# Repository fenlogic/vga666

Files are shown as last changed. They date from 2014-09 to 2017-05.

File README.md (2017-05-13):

# vga666

Passive VGA adapter 666 for Raspberry-Pi B+

## Licence

VGA adaptor for the Raspberry-Pi computer.

Copyright © 2014 Fen Logic Ltd. 

This document and the related databases are free: you can redistribute it and/or modify it under the terms of the GNU General Public License as published by the Free Software Foundation, either version 3 of the License, or any later version. This document and the related databases are distributed in the hope that it will be useful, but WITHOUT ANY WARRANTY; without even the implied warranty of MERCHANTABILITY or FITNESS FOR A PARTICULAR PURPOSE. See the GNU General Public License for more details. You should have received a copy of the GNU General Public License along with this database. If not, see http://www.gnu.org/licenses/

## Usage

For the latest information how to use the VGA adapter see: 
https://www.raspberrypi.org/forums/viewtopic.php?f=91&t=94424&start=125#p657497

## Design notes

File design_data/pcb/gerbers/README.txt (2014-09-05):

bot.pho : Copper bottom.
dd.pho  : Drill data.
smb.pho : Solder mask bottom.
smt.pho : Solder mask top.
ssb.pho : Silkscreen bottom.
sst.pho : Silkscreen top
top.pho : Copper top.

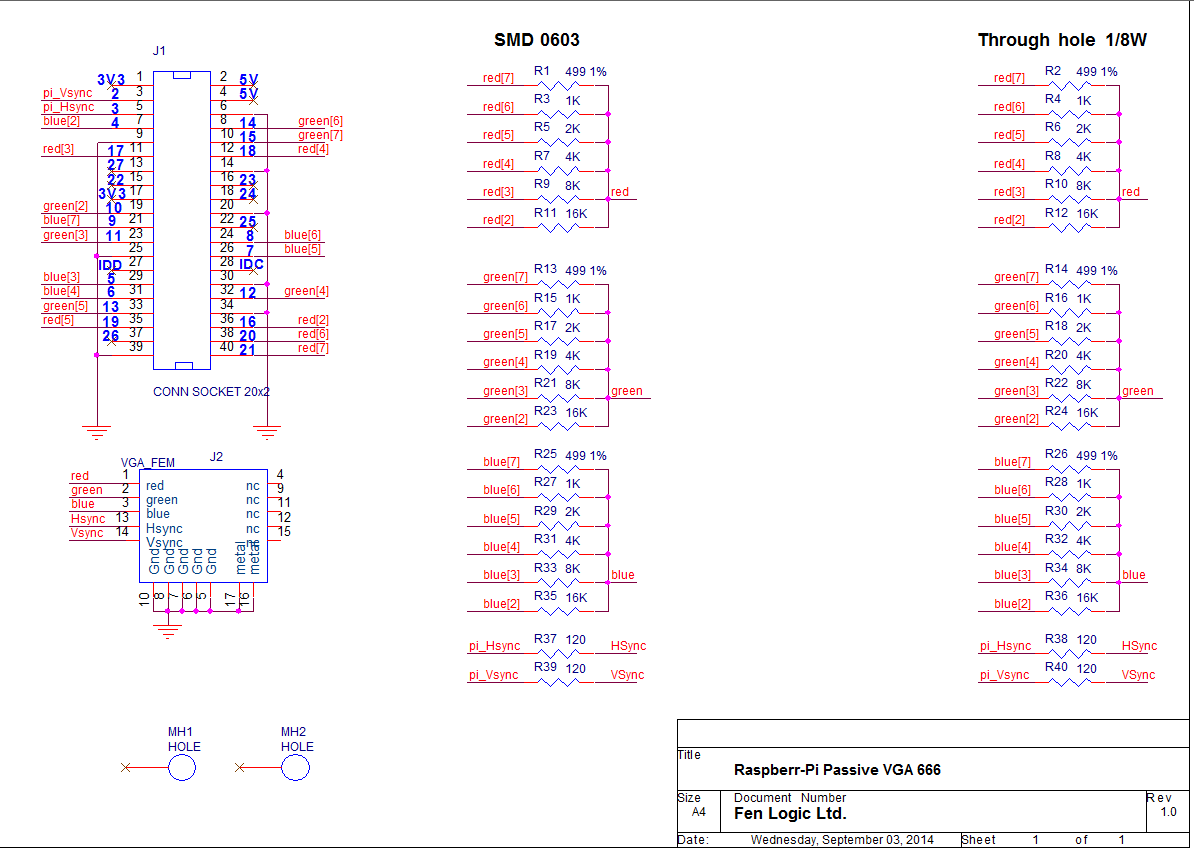
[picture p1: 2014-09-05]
design_data/schematic/vga.gif

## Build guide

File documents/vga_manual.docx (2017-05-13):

Raspberry-Pi VGA

Fen Logic Ltd.

8 September 2014

G.J. van Loo

# Introduction

The GNU GPLv3 license is applicable to this manual and the related databases:

VGA adaptor for the Raspberry-Pi computer.

Copyright © 2014 Fen Logic Ltd.

This document and the related databases are free: you can redistribute it and/or modify it under the terms of the GNU General Public License as published by the Free Software Foundation, either version 3 of the License, or any later version. This document and the related databases are distributed in the hope that it will be useful, but WITHOUT ANY WARRANTY; without even the implied warranty of MERCHANTABILITY or FITNESS FOR A PARTICULAR PURPOSE. See the GNU General Public License for more details. You should have received a copy of the GNU General Public License along with this database. If not, see http://www.gnu.org/licenses/

Thus like with the GNU software, you can replicate this hardware, make derivatives etc. All I ask is that the original designer (Fen Logic Ltd.) gets mentioned in any direct or indirect copies of this work. Note that the GPLv3 mentions: "The GNU General Public License is a free, copyleft license for software and other kinds of works." For contact about this document and/or the databases: info@fenlogic.com.

The adapter (all SMD resistors are at the other side of the board)

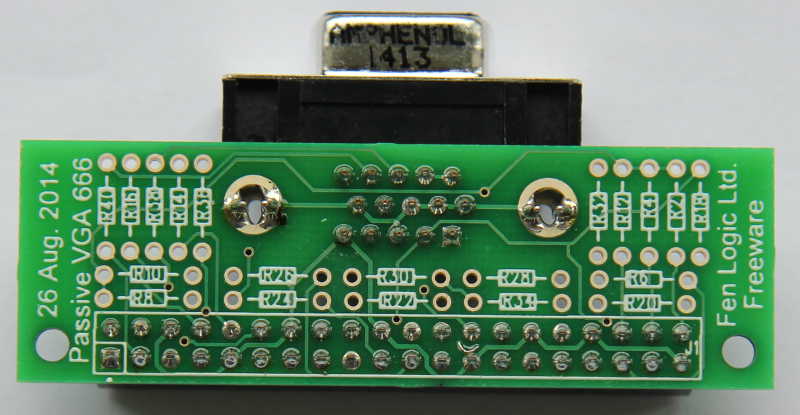
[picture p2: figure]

# Information

VGA

From the birth of the Raspberry-Pi there have been complaints about the lack of a VGA output. That has now been remedied. But only for the B+ and at the cost of losing most of your GPIOs.

The BCM2835 has a parallel display interface on the GPIO pins. I did not publish this in the 2835 datasheet as 50% of the DPI pins where not on the GPIO connector, making it impossible to get any decent video out. The B+ however has all of the necessary DPI signals brought out. Dom has been working on the software side and the new DPI (read: VGA) driver software has been added to the latest release.

Resolution & Quality

The VGA output supports the same resolutions as your HDMI one. Thus from 640x480 up to 1920x1024 60fps. At the highest resolution the pixel quality is almost as good as HDMI. If you look very closely there is a slight pixel crawl. The adapter uses a simple resistor ladder network as digital-to-analogue converter. Therefore the colour quality depends on how well balanced your resistors are. The video shown uses an adapter with 1% SMD resistors. There is a slight colour banding and with 6 bits per channel you have a maximum of 262144 colours.

Double screen

In contrast to the composite video, the DPI interface can be run independent of the HDMI. Thus next to the HDMI screen, the VGA can be used as ‘second monitor’. The software for that is still under development but I expect that to arrive in the next two week. Beware that running two screens at maximum resolution will really eat into your SDRAM bandwidth. In fact it has not tried yet, so it might not be possible.

Where to buy

Nowhere: you can’t buy this anywhere for several reasons which you can find in the manual. But you can make it yourself, or find yourself an enthusiastic partner and have it made. All the data is in the public domain at Github: https://github.com/fenlogic/vga666 . Besides the usual: (Manual, schematics), you will also find the data base for the PCB and the Gerber files. The PCB design supports both through-hole and SMD parts. The design consists of:

- 1 PCB
- 2 connectors
- 20 resistor.

The cost is not prohibited but having a single PCB made is rather expensive so you might want to collect a group of interested people and order a batch. I expect in due time that a far-east manufacturer sees fit to sell them for two dollars. (Batteries not included).

I am in contact with a PCB manufacturer who might put the PCB in their on-line shop for direct purchase.

## Design

The design database consists of:

- design_data/schematic/vga.opj Cadence 16.6 project file
- design_data/schematic/vga.dsn Cadence 16.6 schematics database
- design_data/schematic/vga.gif Screendump of schematic.
- design_data/pcb/VGA.pcb Pads 9.4 PCB database
- design_data/pcb/gerbers/* gerber files, RS-274-X format & readme.
- documents/vga_manual.docx This manual (word 2013)
- documents/vga_manual.pdf This manual (pdf).

## Notes

The schematic below shows two columns of resistors. You can mix through-hole or SMD but for each signal you should mount only one resistor. Thus one of R1 or R2. One of R3 or R4 etc.

The design violates the GPIO specification. You should not draw more than 16mA from a pin. Thus the minimum resistor is 3.3/0.016 = 206 Ohms. But you will notice that the HSYNC and VSYNC resistor are less. I tried 200 Ohm but found that it does not work on some monitors. On the prototype I used 100 Ohm resistors, you might even have to go down to 80 ohms.

The PCB is NOT EMC tested and is likely to radiate a lot. Fortunately the EMC rules do not apply for home-made electronics. But still you might keep it away from sensitive electronics.

The quality from the colours greatly depends on how accurate your resistors are. Certainly the 499 Ohm should be 1% accurate. You might want to use 500Ohm instead but at 1% that is about the same as 499Ohm. The 500 Ohm ones are a lot more difficult (and expensive) to obtain.

## Calculations

If you use a different number of GPIO pins the resistor values have to change. These calculations might help you with that. The impedance of a VGA monitors is 75 Ohms for the colour signals. The Raspberry-Pi has 3.3 volts coming out of the GPIO pins. The VGA colours signal should be 700mV. From that we can calculate what the series resistor should be: Rs = 3.3/0.7*75-75 = 278 Ohms. The series resistors are split into 6 values in the ratio of 1:2:4:8:16:32. These values are placed in parallel.

1/Rs = 1/x + 1/2x + 1/4x + 1/8x + 1/16x + 1/32x A bit of maths gives us that x = 547 Ohms. Thus officially we need resistor value of 547, 1094, 2189, 4378, 8757, 17514 ohms. But those are difficult to obtain so I rounded down to 500, 1K, 2K, 4K, 8K and 16K.

The value of the Hsync and Vsycn resistors have been determined empirical.

## FAQ

How much CPU power does it use?

Non more than the HDMI output. The video signal is generated by the DPI peripheral, not by bit-bashing the GPIO pins. However the DPI interface has a much shallower FIFO and thus it is more likely that the driver does not gets its data in time from the SDRAM (underrun). This shows up as a horizontal ‘hick-up’ on the screen.

How many GPIO pins does it use?

It uses the GPIO pins 2-21. Thus you only have 6 GPIO pins left: 22..27.

Can I use it on the A or B?

No, it only works on the B+. It is no so much the number of GPIO pins required, the right GPIO pins are required. The VGA output must have access to at least the MS bits of each colour channel and on the A and B these are not on the GPIO header for all three colours.

Can I use it with the computer module?

The board will not plug into the computer module as that does not have a GPIO header. But you can connect the GPIO pins as in the schematic.

Does it work with Minecraft?

Yes, although Minecraft on the Pi writes directly to an image buffer the VGA handling is the same as the HDMI. (Yes, I tried it :-)

Can I have two independent screens?

Ultimately yes. At the moment the drivers for two independent screens are under development. (In the demo video we cheated a bit). . Running two screens (or three with the DSI screen?) will use up a lot of SDRAM bandwidth and not all resolutions on all screens will be possible.

Will it work for XBMC?

Yes, I have been told the change are already in the latest release.

Can I reduce the number of GPIO pins it uses?

Yes. You can drop the LS colours bits of each channel which will free up more GPIO pins but the picture quality will get worse as you lose more colours. If you use less resistors you also have to adapt the values. (See section: Calculations).

Bits/channel | Colours
6 | 262144
5 | 32768
4 | 4096
3 | 512
2 | 64
1 | 8

Schematic:

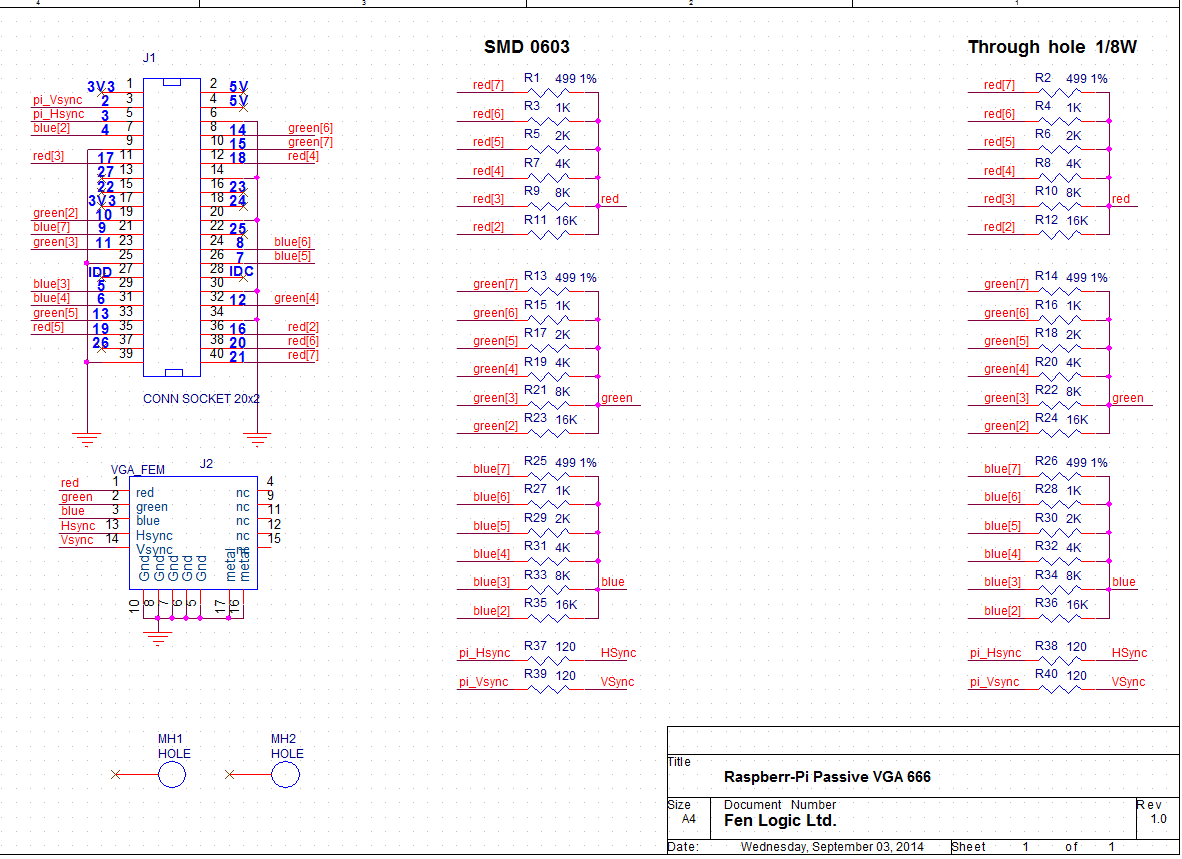
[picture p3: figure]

## Parts:

J1: Female connector 2x20 pins, 0.1” pitch, straight, through hole.

J2: Female D-sub 15 pins, angled, VGA pin pattern. I don’t know in how far all VGA connectors have the same footprint. I used a VGA connector from Farnell: 2401183.
(AMPHENOL L77HDE15SD1CH4R).

Rx: Resistor 1/8W 1%, values as in schematic.

## Installation

~~Run rpi-update.~~

~~Copy~~ ~~the file~~ ~~dt-blob-dpi.bin to boot partition of sdcard, renaming it to dt-blob.bin~~

~~(The file is part~~ ~~of the git-hub data~~~~base download~~~~: setup/dt-blob-dpi.bin~~~~).~~

~~Don’t forget that the dt-blob.bin will disable all GPIOs 2-21 for any other use. Thus if you switch back to HDMI you might also want to give the dt-blob.bin file a different name.~~

~~Add this to config.txt~~

~~enable_dpi_lcd=1~~

~~display_default_lcd=1~~

~~You should now be able to boot with VGA resolution on VGA connector.~~

~~You can change resolution with, e.g.~~

~~dpi_group=2~~

~~dpi_mode=82~~

~~(~~~~for 1080p60.~~ ~~)~~

~~Or:~~

~~dpi_group=2~~

~~dpi_mode=86~~

~~(for 1366x768@60)~~

~~You should notice that these settings are identical to the HDMI settings.~~

All new operating systems for the Raspberry-Pi now support the VGA adapter. This can change in small ways in new software versions. For the latest information how to set-up and use the adapter see:

https://www.raspberrypi.org/forums/viewtopic.php?f=91&t=94424&start=125#p657497

The DPI interface (which we use to make the VGA signal) can work in different colour modes. The default mode is 666 (6 Red, 6 Green, 6 Blue colours). Other supported formats are: 565 (5 Red, 6 Green, 5 Blue colours) and 888 (8 Red, 8 Green, 8 Blue colours). Also there are different ways in which the 666 and 565 colours bits can be output on the GPIO line. Please see the table below.

Mode | RGB bits | GPIO
| | 27 | 26 | 25 | 24 | 23 | 22 | 21 | 20 | 19 | 18 | 17 | 16 | 15 | 14 | 13 | 12 | 11 | 10 | 9 | 8 | 7 | 6 | 5 | 4
1 | - | - | - | - | - | - | - | - | - | - | - | - | - | - | - | - | - | - | - | - | - | - | - | - | -
2 | 565 | - | - | - | - | - | - | - | - | 7 | 6 | 5 | 4 | 3 | 7 | 6 | 5 | 4 | 3 | 2 | 7 | 6 | 5 | 4 | 3
3 | 565 | - | - | - | 7 | 6 | 5 | 4 | 3 | - | - | 7 | 6 | 5 | 4 | 3 | 2 | - | - | - | 7 | 6 | 5 | 4 | 3
4 | 565 | - | - | 7 | 6 | 5 | 4 | 3 | - | - | - | 7 | 6 | 5 | 4 | 3 | 2 | - | - | 7 | 6 | 5 | 4 | 3 | -
5 | 666 | - | - | - | - | - | - | 7 | 6 | 5 | 4 | 3 | 2 | 7 | 6 | 5 | 4 | 3 | 2 | 7 | 6 | 5 | 4 | 3 | 2
6 | 666 | - | - | 7 | 6 | 5 | 4 | 3 | 2 | - | - | 7 | 6 | 5 | 4 | 3 | 2 | - | - | 7 | 6 | 5 | 4 | 3 | 2
7 | 888 | 7 | 6 | 5 | 4 | 3 | 2 | 1 | 0 | 7 | 6 | 5 | 4 | 3 | 2 | 1 | 0 | 7 | 6 | 5 | 4 | 3 | 2 | 1 | 0

You select the mode using: dpi_output_format=X (X in range 1..7)

The VGA adaptor PCB is designed up for mode 5.

## Assembly:

First mount all the resistors, then the connectors.

Make sure you enter the connectors from the right side! The connectors are at the same side as the surface mount resistors.

I have made a colour diagram to indicate where the resistors go as the silkscreen was un readable on my PCBs.:

SMD side (And connector side).

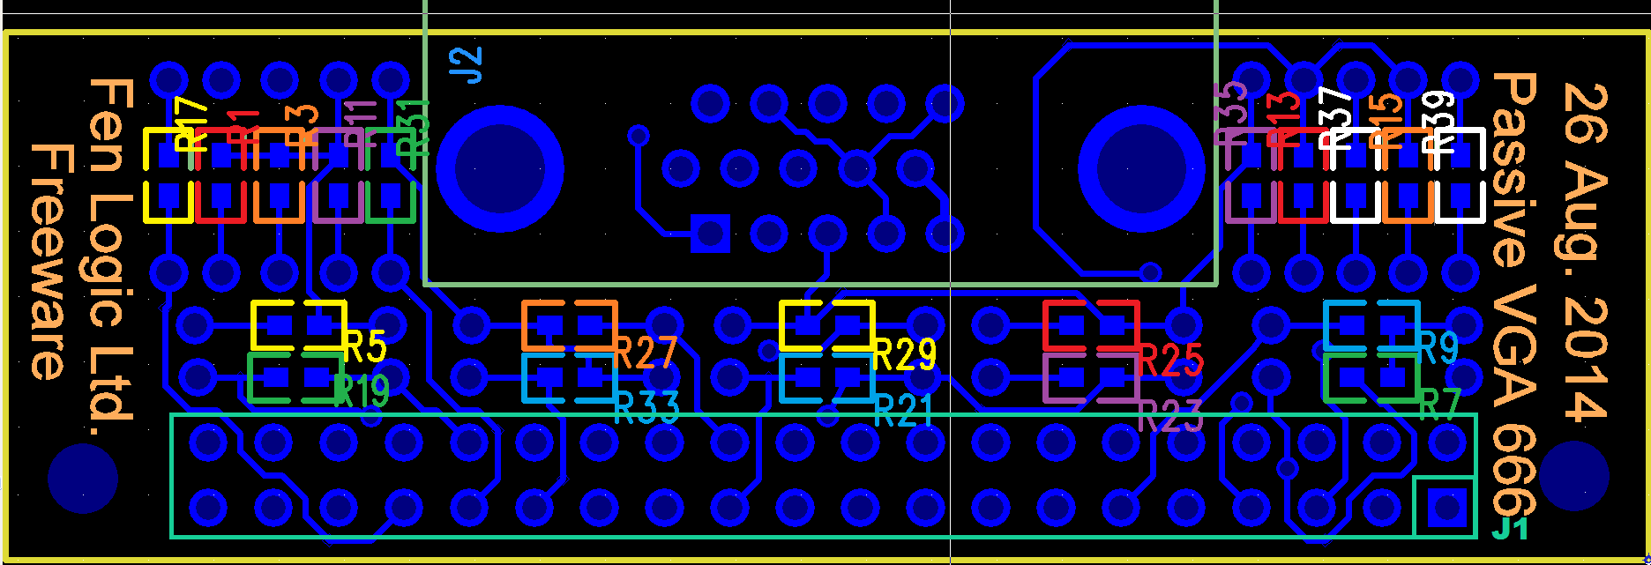
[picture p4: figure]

Through-hole side:

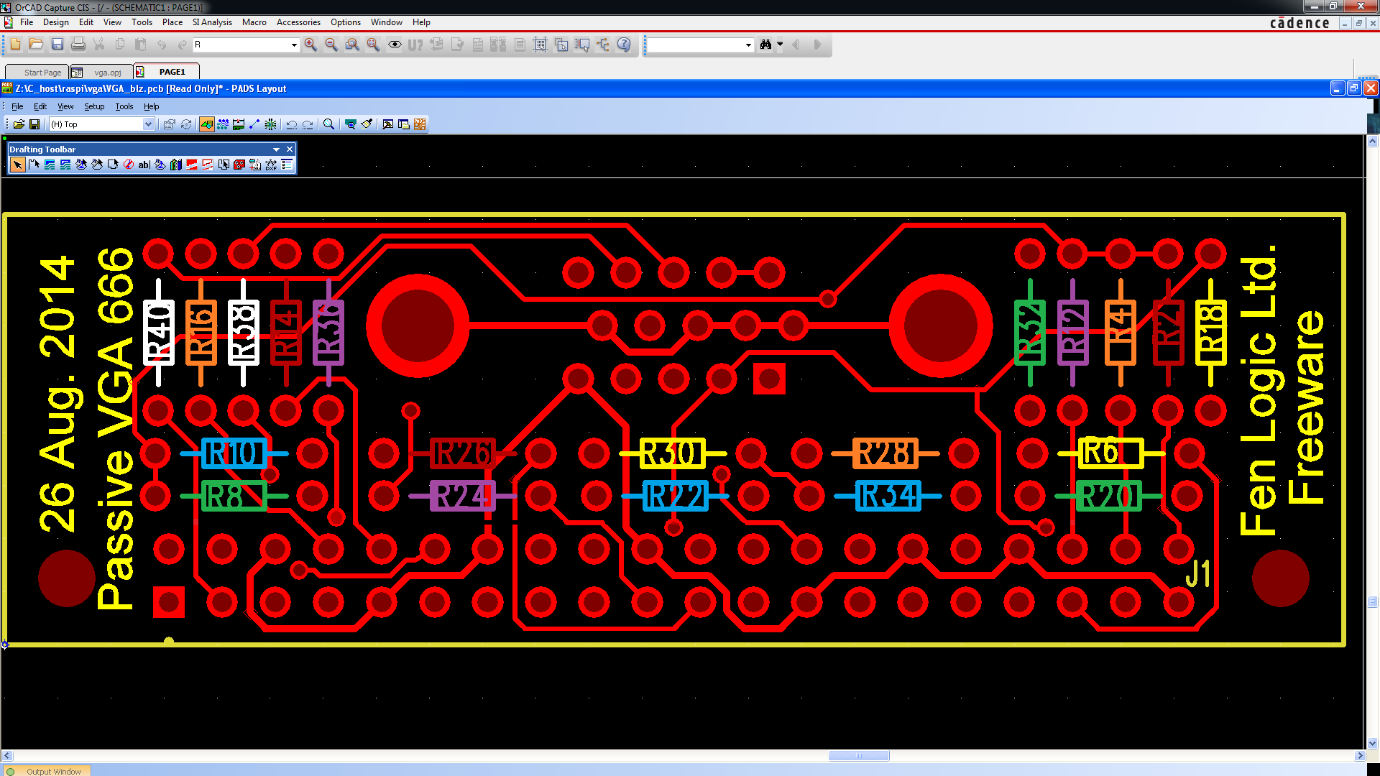
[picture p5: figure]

Red = 499 Ohm

Orange = 1K Ohm

Yellow = 2K Ohm

Green = 4K Ohm

Blue = 8K Ohm

Purple = 16k Ohm

White = 80..120 Ohm

VGA: DPI/VGA adapter for the Raspberry-Pi Rev 1.0, 8 September 2014

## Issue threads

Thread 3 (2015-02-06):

No output

Matty11611, 2015-02-06:
Hi, i like the idea of having two outputs from the Pi B+ however have bought the kit and tested all resistors are in the correct location followed the instructions several times from the manual and still no output, bought a new add on board and still nothing even after a fresh install and doing every step again. currently bought 2 add on boards with no success, please help, its part of my final year group project and i cant afford the time learning coding to work out where im going wrong. can i also add i found something about blacklisting which i have also done still with no joy, any other suggestions would be much appreciated, i have tried on 2 seprate vga monitors with different resolutions to no avail :(

gertvanloo, 2015-02-06:
Matty, I would love to help you but that is impossible. There are just too many ways in which it does not work. The first step towards a solution is to take an oscilloscope and check if you have signals on the pins, especially the hsync and vsync. It is also better to post your problem on the VGA section of Raspberry-Pi forum as a lot more people then just I alone can offer advise.

Matty11611, 2015-02-12:
Hi, been onto the rpi fourm and it seems to be an issue with the latest version of raspbian is there a fix coming soon for this to support the latest raspian release, thanks

Matty11611, 2015-02-14:
Gert, thanks for directing me over to RPI fourm, i have finally got it working, theres something wrong with the compatibilty of the VGA adapter with the last 2 versions of the raspbian, not sure if theres an extra step to be added or the dt-blob.bin file to be edited, also on your video it shows compatibilty for 2 screens, hdmi and VGA how can this be enabled, thanks

Closed 2015-02-26.

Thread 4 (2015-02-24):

Dual Screen

Matty11611, 2015-02-24:
Gert, just wondering if there is going to be any software available soon to enable both HDMI and VGA simultaneously, im currently trying to run impress with notes on the VGA screen with the os booting on vga and then get the ppt to run on the hdmi output, but dont really need it to be seen until the ppt is started, any ideas?

gertvanloo, 2015-02-26:
Matty, software to do that has been available from the beginning.
However as with all SW for the VGA adapter you have to ask the Raspberry-Pi Foundation if you are having any issues.

Matty11611, 2015-02-27:
I cant see s single place on there forum where you can download the software to make a global second monitor all I have found which forces dual screen using this is omxplayer, even using impress and a selection of display numbers still nothing even though the comand is of the same format as omxplayer

alkemir, 2016-09-30:
Dear Matty,
this might be a bit late, but check out https://github.com/alkemir/gertCloner
I don't know if we re-wrote the wheel here, but as you, I could not find a way to use
the VGA as a dual display. This is a step in that direction, not the solution you are asking
for, but maybe somebody will take it from there.

gertvanloo, 2017-02-12:
The latest answer I have from the foundation is here: https://www.raspberrypi.org/forums/viewtopic.php?f=91&t=94424#p1104476

alkemir, 2017-02-12:
Hi Gert! Nice to hear from you. I will continue the discussion there,
hopefully Dom can assist us, I feel we are close to achieving extended
dualscreen for the RPi.

Closed 2015-02-26.

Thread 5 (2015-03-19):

setup/dt-blob-dpi.dts does not have references to the Pi2

robertely, 2015-03-19:
dt-blob-dpi.dts does not have a stanza for the Raspberry Pi 2. Preventing this from working.

I've been trying to find a device tree with a video core config for the Pi 2 but I can't find enough information.

gertvanloo, 2015-03-19:
I do not have any control over the software. I know the VGA adapter was tested with the Pi-2 as I have seen it working with one of the production prototypes. As far as I know the drivers are part of the standard image. For all other matters post at "http://www.raspberrypi.org/forums/viewtopic.php?f=100&t=86658"

6by9, 2015-06-02:
Pi2 has used the bplus pins config until the firmware commit https://github.com/Hexxeh/rpi-firmware/commit/a1621d67b20f04acdac602d0b24923ec3cdbfb66 on 30th May.
Things have just changed - Phil is on it. (I've hit the issue when linking to a DPI screen via an Adafruit Kippah)

pelwell, 2015-06-03:
The new dt-blob has more configurations, each of which has a few more defines:
* rev1
* rev2
* bplus1 // Pi 1 Model B+ rev 1.1
* bplus2 // Pi 1 Model B+ rev 1.2
* aplus
* 2b1 // Pi 2 Model B rev 1.0
* 2b2 // Pi 2 Model B rev 1.1
* cm

The reason for the change has been to document the variations in hardware and to replace some of the board-specific code with additional usage of the pin configuration data.

It's a shame that the external dt-blob is a complete replacement for the internal one rather than a patch to it, but changing that isn't something to do in a hurry. Instead, we've uploaded the new structure [here](https://github.com/raspberrypi/documentation/blob/master/configuration/images/dt-blob.dts), and  you just need to overwrite pins 2-21 for the 5 (sorry) configurations for B+-compatible boards.

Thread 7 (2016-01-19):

Pi zero seems unsupported

fasmide, 2016-01-19:
Hi

Ive tried downloading your dt-blob.bin, putting it in /boot and added

```
enable_dpi_lcd=1
display_default_lcd=1
dpi_group=2
dpi_mode=4
```

to `/boot/config.txt` - However im unable to find any V of H sync signals (with an oscilloscope) where they should be according to your diagram (Or at any other pin for that matter :)

Im thinking it could be related to the overlay not getting applied on the zero (I dont know how to debug this) but looking at the device tree source you provided - my guess is that it needs a "pin_zero" section, but im not sure what the pi zero is called though, looking in`/sys/firmware/devicetree/base`  does not get me anywhere:

```
pi@raspberrypi:/sys/firmware/devicetree/base $ cat name
pi@raspberrypi:/sys/firmware/devicetree/base $ cat model
Raspberry Pi ? Rev 1.2
```

AndrewFromMelbourne, 2016-01-20:
Have a look at the (instructions on the Raspberry Pi forum)[https://www.raspberrypi.org/forums/viewtopic.php?p=657497#p657497], you don't need the dt-blob.bin any longer.

fasmide, 2016-01-20:
@AndrewFromMelbourne Thanks for pointing me in the right direction - ive managed to get it working :)

Closed 2017-02-12.

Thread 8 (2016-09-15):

Gerbers

qwertymodo, 2016-09-15:
I can't seem to load the gerber files in any of the gerber viewers I use, and OSHPark won't accept them either.  For one thing, most fab houses want their drill layer in Excellon format, and also, OSHPark requires a board outline on a separate layer.  I'm not sure what the issues with the other layers are, but I'm still looking into it, and I'll report back if I can figure it out.

qwertymodo, 2016-09-15:
Also, can you document what application should be used to open the .pcb file?  That file extension is used by a dozen different CAD applications, and I can't find any particularly useful information inside the file itself to tell me which one I should be using.

gertvanloo, 2017-05-13:
Pentalogix have a free gerber viewer (viewmate) which can handle these files as I use it myself.

Closed 2017-05-13.

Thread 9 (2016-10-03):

Tweak output of the VGA to other formats

vonj, 2016-10-03:
So, people, this got me thinking. Sorry if this is entirely the wrong place for this post. If so, any pointers welcome.

Anyhow, since it apparently is so easy (hardware wise, anyway) to make a VGA output from the Raspberry, can this approach be tweaked to do:

1)

15 kHz RGB output?  This way, Raspberry Pi could drive arcade and TV monitors for faithful emulation of old video games but with greater color separation than you get from the built in composite output.

2)
SVIDEO output. https://en.wikipedia.org/wiki/S-Video

3)
Composite video. (I know, maybe pointless considering the raspi already has one built in.)
https://en.wikipedia.org/wiki/Composite_video

4)
Drive the deflectors on an old black and white monitor/TV (X & Y) and video intensity directly?

I don't expect anyone to do these things for me, but would be very happy for any insights into how  this VGA thing is implemented on the Raspberry.

Where is all the magic happening? In the "bin" file? Where can I start tweaking settings and experiment with the output I get?

(For all of these output formats I am more interested in black/white output rather than color, if that helps.)

Antiriad, 2016-11-05:
Hi @vonj,
what you are asking in number 1 is yet doable with VGA 666:
[https://www.youtube.com/watch?v=gjUBQKyeWlQ](https://www.youtube.com/watch?v=gjUBQKyeWlQ)

And of course you can get a true RGB output on TV with a correct VGA - SCART cable. ;)

However, there seems to be an issue / limitation with the VGA 666 and pixel clock:
[https://www.raspberrypi.org/forums/viewtopic.php?p=1029349#p1029349](https://www.raspberrypi.org/forums/viewtopic.php?p=1029349#p1029349)

I really hope @gertvanloo  take a look at this post ...
Thanks! :)

vonj, 2016-11-11:
Thank you so much @Antiriad.

cedricp, 2018-08-29:
Hi,
Congratulation for this work. I'm interested in this project to drive an old CGA LCD monitor, but I would like to keep SPI pins free. I don't care losing color resolution, but I didn't find any documentation to setup the dts file.
Thank you.

gertvanloo, 2018-08-30:
No, the SPI interface uses GPIO 8-11 and those are the MS bits of the BLUE channel in all DPI modes.
You can drop LS bits but the MS bit(s) are required. The minimum is 8 colours using only the MS bit of each channel.
If you are desperate you can implement PIS using bit-banging.

cedricp, 2018-08-30:
Too bad ! I'll use a HW converter instead, thank you.

Closed 2018-08-30.

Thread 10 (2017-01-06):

Setup and Driver

Synoia, 2017-01-06:
Could you please post a link to the setup instructions and driver download information?

Thanks

gertvanloo, 2017-01-07:
There is nothing to download or install. The drivers are part of the Raspberrypi software.
For all matters related to software go to the Raspberry-Pi website: www.raspberrypi.org
You also have to look there for resolution, bit clock etc.

There is a section in the beginners forum which answers most VGA questions:
www.raspberrypi.org/forums/viewtopic.php?f=91&t=94424

Closed 2017-01-07.

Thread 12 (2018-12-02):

the GPIO21

melaymei, 2018-12-02:
I want to use the GPIO 21 for I2S out.
but it be used in DPI RGB565.
Can i change the DPI pin?
Sorry for my poor english.

gertvanloo, 2018-12-02:
The DPI outputs are  hard coded . You can find them in [this ]( https://www.raspberrypi.org/forums/viewtopic.php?f=91&t=94424&sid=acaa30a75f1b601c9fb88893efcb99e8#p1238180) table.
You have several options:
1/  Use DPI mode 2. (565 mode)
2/  Use DPI mode 4 (565 mode) and loose RED colour bit 3. Reduces the number of colours.
3/  Use DPI mode 6 (666) and loose RED colour bit 2 and 3. Reduces the number of colours.
4/  Use DPI mode 7. (Don't use bits 0 or 1 of any colour)
In all cases you have to wire up your own VGA connector.

Closed 2018-12-02.

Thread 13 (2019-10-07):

Flickering with VGA666 on Raspbian Buster

alessioscand, 2019-10-07:
Hello,
the picture of a VGA666 on Raspbian Buster (Raspberry Pi 4) it's flickering like this:
https://youtu.be/5f5hpGrPpZk

I've tested different settings (resolution, refresh, video driver etc.) and even different hardware (GPIO cable, VGA666) but the problem persist.

Thank you.

gertvanloo, 2019-10-07:
This is a known issue. It is mentioned in the assembly manual as "bit crawl". The cause is the cross-over talk between the various analogue signals. It gets worse with longer cables and higher frequencies. Some monitors are more susceptible then others.

alessioscand, 2019-10-07:
Thank you for your feedback. If this is the problem ("bitcrawl") why does it happen only on Raspbian Buster and/or RPi 4, and not on Raspbian Stretch / RPi 3?
I'm using same monitor and same parts.

linuxenko, 2020-03-07:
Hi @alessioscand. Did you make it work properly on RPI 4 ?

Closed 2019-10-07.

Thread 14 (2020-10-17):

VGA888 Information

TechieAndroid, 2020-10-17:
I believe there currently is a lack of organized information regarding how one would implement the additional resistors required for 8bits per channel. The 888 would require 6 extra resistors in total, 2 per channel.

If the current method is expanded upon I guess they would be 32K and 64K respectively?

Also since they're in parallel I'm guessing that they would connect to the same R/G/B channels respectively as the regular 666 resistors do. Then on the GPIO R would be pins 26&27 G pins 18&19 and B pins 6&7.

Am I right?

Also would the pi recognize it as a 888 vga hat or would one need to alter some part of the boot config as well?

I just kinda pieced this information together from random parts of the vga manual so if anyone can clear this up I'd really appreciate it.

gertvanloo, 2020-10-17:
It is not just  a matter of adding more resistors. The 6 bit was chosen because of the tolerances of resistors. With 6 bits the tolerance has to be better then 1/64 (1.56% accuracy) which is do-able with 1% resistors. If not you get "colour banding". For 8 bit you would need 1/256 or better then 0.39%. Those are very difficult to obtain. Note that the accuracy is most critical in the larger resistor values.

TechieAndroid, 2020-10-17:
Thanks, that clears things up for me.

Closed 2020-10-17.

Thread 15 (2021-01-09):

VGA Pins 4, 9, 11, 12, and 15 - "nc" means "connected together"

6by9, 2021-01-09:
I know this is pretty much a dead project, but logging for information.

Schematic lists the above pins on the 15pin-HD D as "nc", which normally means "not connected".

PCB design has connected them all together, presumably as a net called "nc"!

That caused me a fair amount of head scratching when I was trying to hook I2C level shifters onto pins 12 &15 from Pi GPIOs 0&1 to be able to read the display EDID (works quite nicely).

gertvanloo, 2021-01-10:
I am rather surprised. I have never noticed that those pins where interconnected. In the schematic they do not have a net name. (the NC is  just a label on  of the VGA connector) and as such they **_should_** have been unconnected. In my blind faith of the CAD tools I must have routed aall traces as shown to me by the PCB tool without checking them against the schematic. You are right, there is no need or reason why they should be connected together.

Closed 2021-01-10.

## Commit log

2014-09-05 design data as used for prototype PCBs
    [VGA.DSN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]
2014-09-05 GPIO configuration files as received from Dom. These must be placed in the Raspberry-Pi /boot directory for the VGA adapter to work.
2017-05-13 Update README.md
    Added link to relevant section on the Raspberry-Pi website.
2017-05-13 For installation now referring to the Raspberry-Pi website
    Installation text removed as Raspberry-Pi development has moved on.
    Now referring to the Raspberry-Pi website: https://www.raspberrypi.org/forums/viewtopic.php?f=91&t=94424&start=125#p657497
